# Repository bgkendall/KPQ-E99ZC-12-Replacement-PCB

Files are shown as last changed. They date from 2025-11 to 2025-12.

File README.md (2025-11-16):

# KPQ-E99ZC-12 Replacement PCB

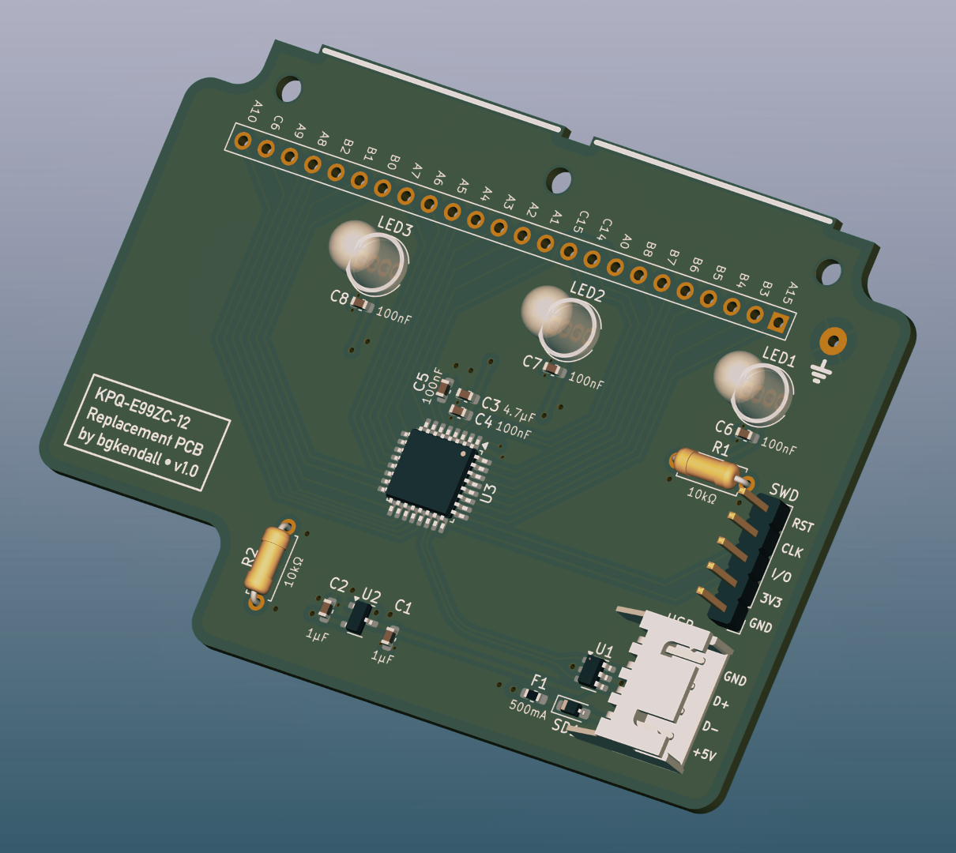
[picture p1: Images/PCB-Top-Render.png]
3D render of PCB viewed from above


## About

This is a replacement PCB for the [Mitsumi KPQ-E99ZC] keyboard of the mid-’90s. This new
PCB uses an STM32C071KBT6 or STM32G0B1KBT6 as the MCU. The pin-outs and behaviour of these
chips are the same and it should be possible to use either chip. The STM32C071 is cheaper,
but is currently (as of November 2025) unsupported by QMK and ZMK.

**CAUTION: Currently this PCB has not been produced and is untested.**

## Requirements

 * [KiCad] v9 or later
 * [BGKiCad library]

[Mitsumi KPQ-E99ZC]: https://web.archive.org/web/20240202015834/https://deskthority.net/wiki/Mitsumi_KPQ-E99ZC
[KiCad]: https://www.kicad.org
[BGKiCad library]: https://github.com/bgkendall/BGKiCad

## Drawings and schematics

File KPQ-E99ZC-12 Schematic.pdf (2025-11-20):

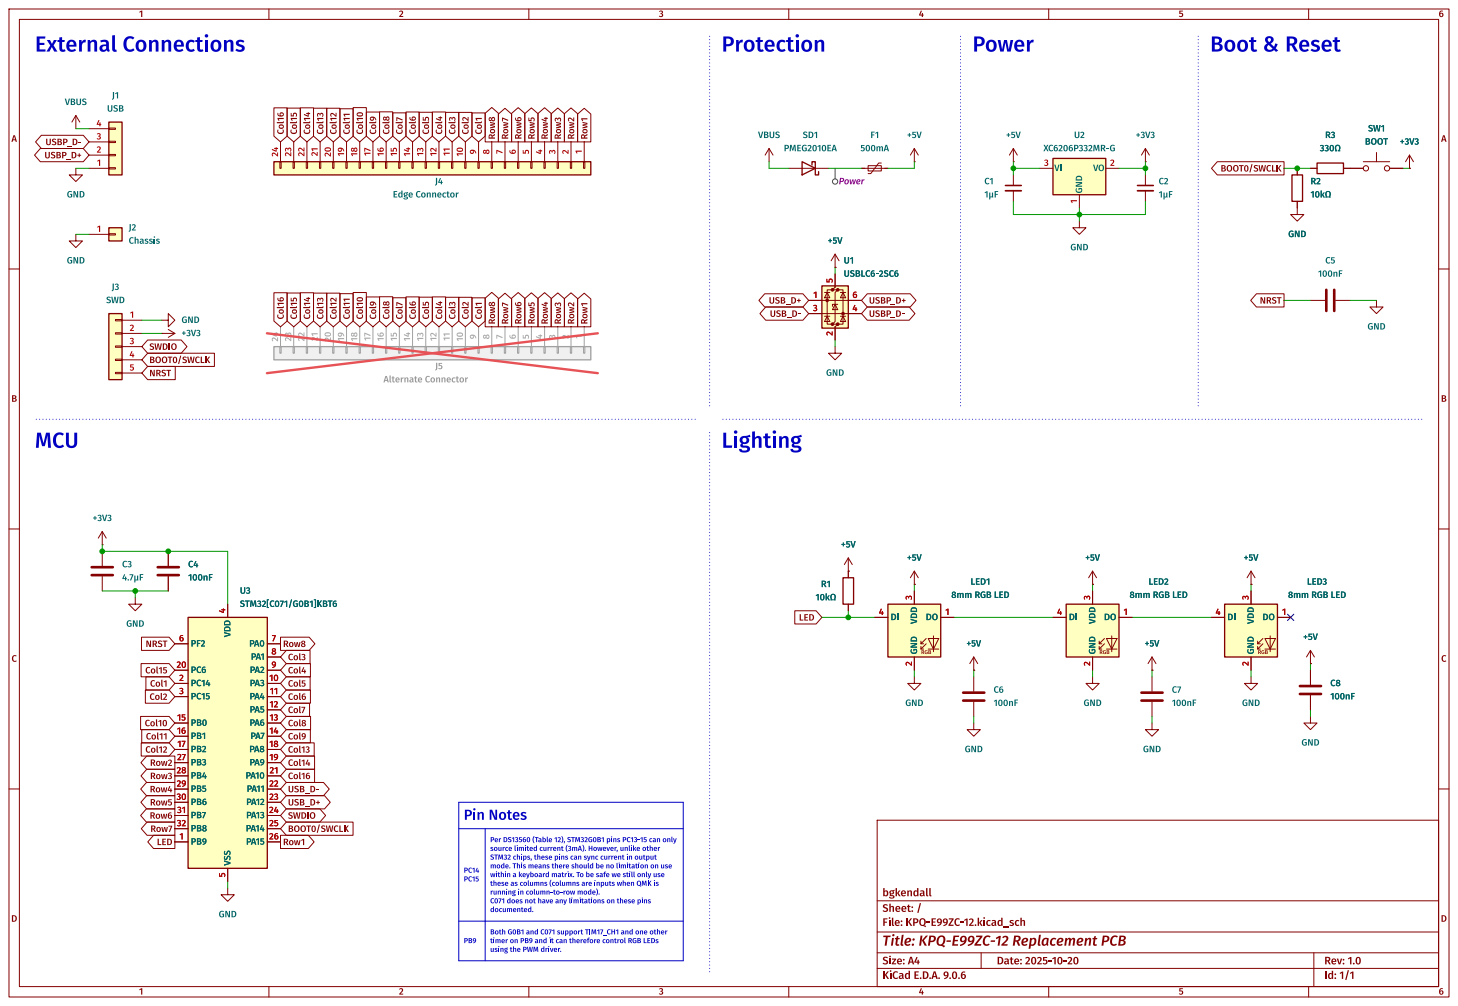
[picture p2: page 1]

source limited current (3mA).However, unlike other STM32chips, these pins can sync current in output mode. This means there should be no limitation on use within a keyboard matrix. Tobe safe we still only use

these as columns (columns are inputs when QMKis

File: KPQ-E99ZC-12.kicad_sch Sheet: / bgkendall

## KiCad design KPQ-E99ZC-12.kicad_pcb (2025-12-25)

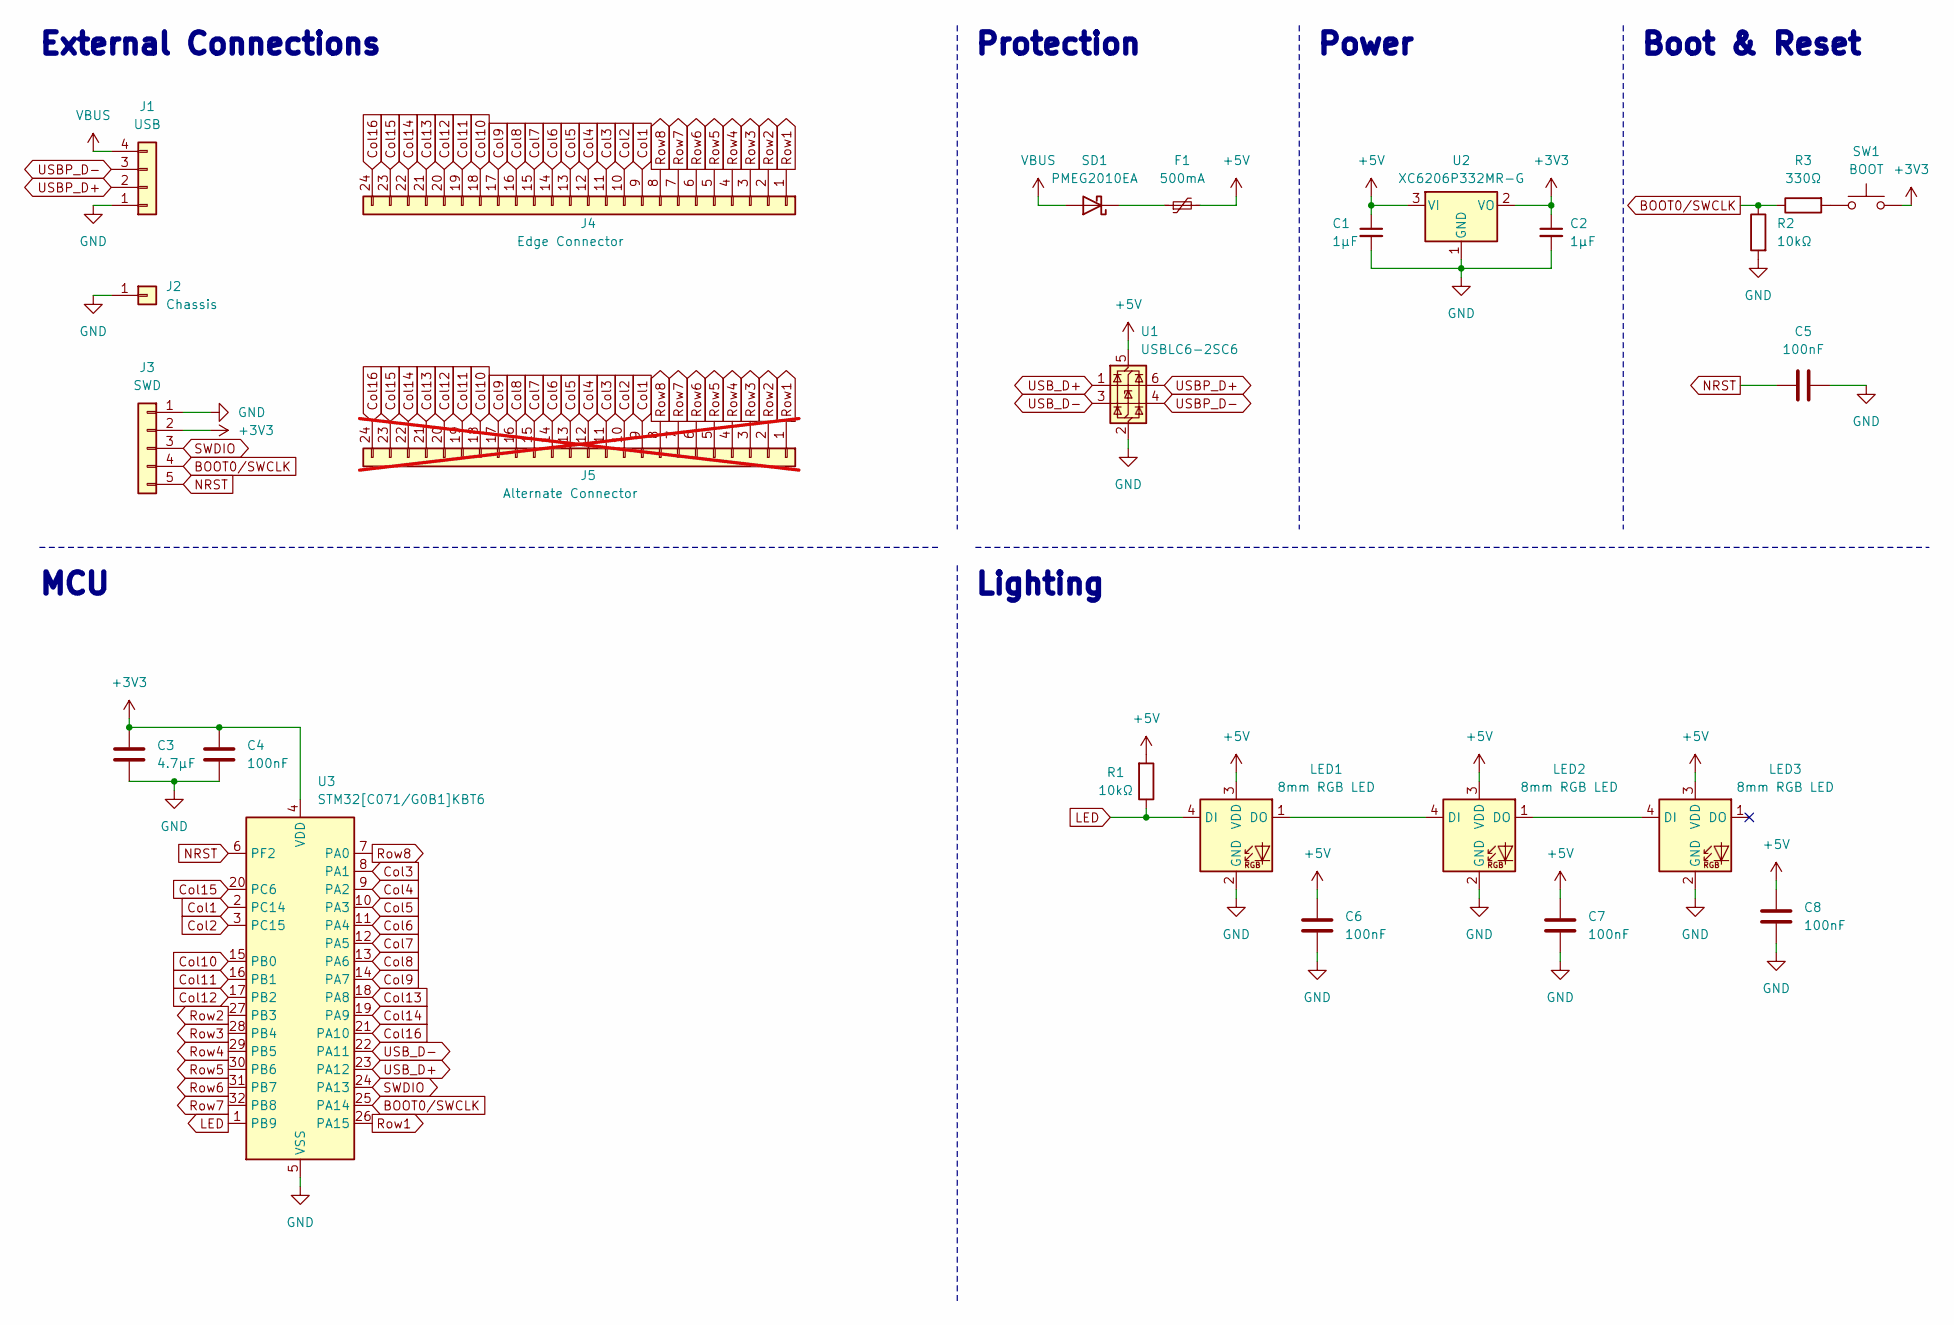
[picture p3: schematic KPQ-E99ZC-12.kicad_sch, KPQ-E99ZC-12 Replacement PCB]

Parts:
C1, C2: 1µF; C_0603_1608Metric; LCSC C52923
C3: 4.7µF; C_0603_1608Metric
C4, C5, C6, C7, C8: 100nF; C_0603_1608Metric
F1: 500mA; Fuse_0603_1608Metric_Pad1.05x0.95mm_HandSolder; LCSC C210357
J1: USB; PinHeader_1x04_P2.54mm_Vertical
J2: Chassis; SolderWire-0.5sqmm_1x01_D0.9mm_OD2.3mm
J3: SWD; PinHeader_1x05_P2.54mm_Vertical
J4: Edge Connector; Edge_Connector_01x24
J5: Alternate Connector; PinHeader_1x24_P2.54mm_Vertical; not fitted
LED1, LED2, LED3: 8mm RGB LED; LED_D5.0mm-4_RGB
R1, R2: 10kΩ; R_Combined_Axial_DIN0207_0603_1608Metric
R3: 330Ω; R_Combined_Axial_DIN0207_0603_1608Metric
SD1: PMEG2010EA; D_SOD-323_HandSoldering; LCSC C2837790
SW1: BOOT; SW_SPST_SKQG_WithStem; LCSC C231329
U1: USBLC6-2SC6; SOT-23-6
U2: XC6206P332MR-G; SOT-23-3
U3: STM32[C071/G0B1]KBT6; LQFP-32_7x7mm_P0.8mm

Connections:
+3V3: C2.1, C3.1, C4.1, J3.2, SW1.2, U2.2 (VO), U3.4 (VDD)
+5V: C1.1, C6.2, C7.2, C8.2, F1.2, LED1.3 (VDD), LED2.3 (VDD), LED3.3 (VDD), R1.2, U1.5 (VBUS), U2.3 (VI)
BOOT0/SWCLK: J3.4, R2.1, R3.1, U3.25 (PA14)
Col1: J4.9, J5.9, U3.2 (PC14)
Col2: J4.10, J5.10, U3.3 (PC15)
Col3: J4.11, J5.11, U3.8 (PA1)
Col4: J4.12, J5.12, U3.9 (PA2)
Col5: J4.13, J5.13, U3.10 (PA3)
Col6: J4.14, J5.14, U3.11 (PA4)
Col7: J4.15, J5.15, U3.12 (PA5)
Col8: J4.16, J5.16, U3.13 (PA6)
Col9: J4.17, J5.17, U3.14 (PA7)
Col10: J4.18, J5.18, U3.15 (PB0)
Col11: J4.19, J5.19, U3.16 (PB1)
Col12: J4.20, J5.20, U3.17 (PB2)
Col13: J4.21, J5.21, U3.18 (PA8)
Col14: J4.22, J5.22, U3.19 (PA9)
Col15: J4.23, J5.23, U3.20 (PC6)
Col16: J4.24, J5.24, U3.21 (PA10)
GND: C1.2, C2.2, C3.2, C4.2, C5.2, C6.1, C7.1, C8.1, J1.1, J2.1, J3.1, LED1.2 (GND), LED2.2 (GND), LED3.2 (GND), R2.2, U1.2 (GND), U2.1 (GND), U3.5 (VSS)
LED: LED1.4 (DI), R1.1, U3.1 (PB9)
NRST: C5.1, J3.5, U3.6 (PF2)
unnamed: LED1.1 (DO), LED2.4 (DI)
unnamed: LED2.1 (DO), LED3.4 (DI)
unnamed: R3.2, SW1.1
unnamed: F1.1, SD1.1 (K)
Row1: J4.1, J5.1, U3.26 (PA15)
Row2: J4.2, J5.2, U3.27 (PB3)
Row3: J4.3, J5.3, U3.28 (PB4)
Row4: J4.4, J5.4, U3.29 (PB5)
Row5: J4.5, J5.5, U3.30 (PB6)
Row6: J4.6, J5.6, U3.31 (PB7)
Row7: J4.7, J5.7, U3.32 (PB8)
Row8: J4.8, J5.8, U3.7 (PA0)
SWDIO: J3.3, U3.24 (PA13)
USBP_D+: J1.2, U1.6 (I/O1)
USBP_D-: J1.3, U1.4 (I/O2)
USB_D+: U1.1 (I/O1), U3.23 (PA12)
USB_D-: U1.3 (I/O2), U3.22 (PA11)
VBUS: J1.4, SD1.2 (A)

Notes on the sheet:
Boot & Reset
MCU
Power
Lighting
Protection
External Connections

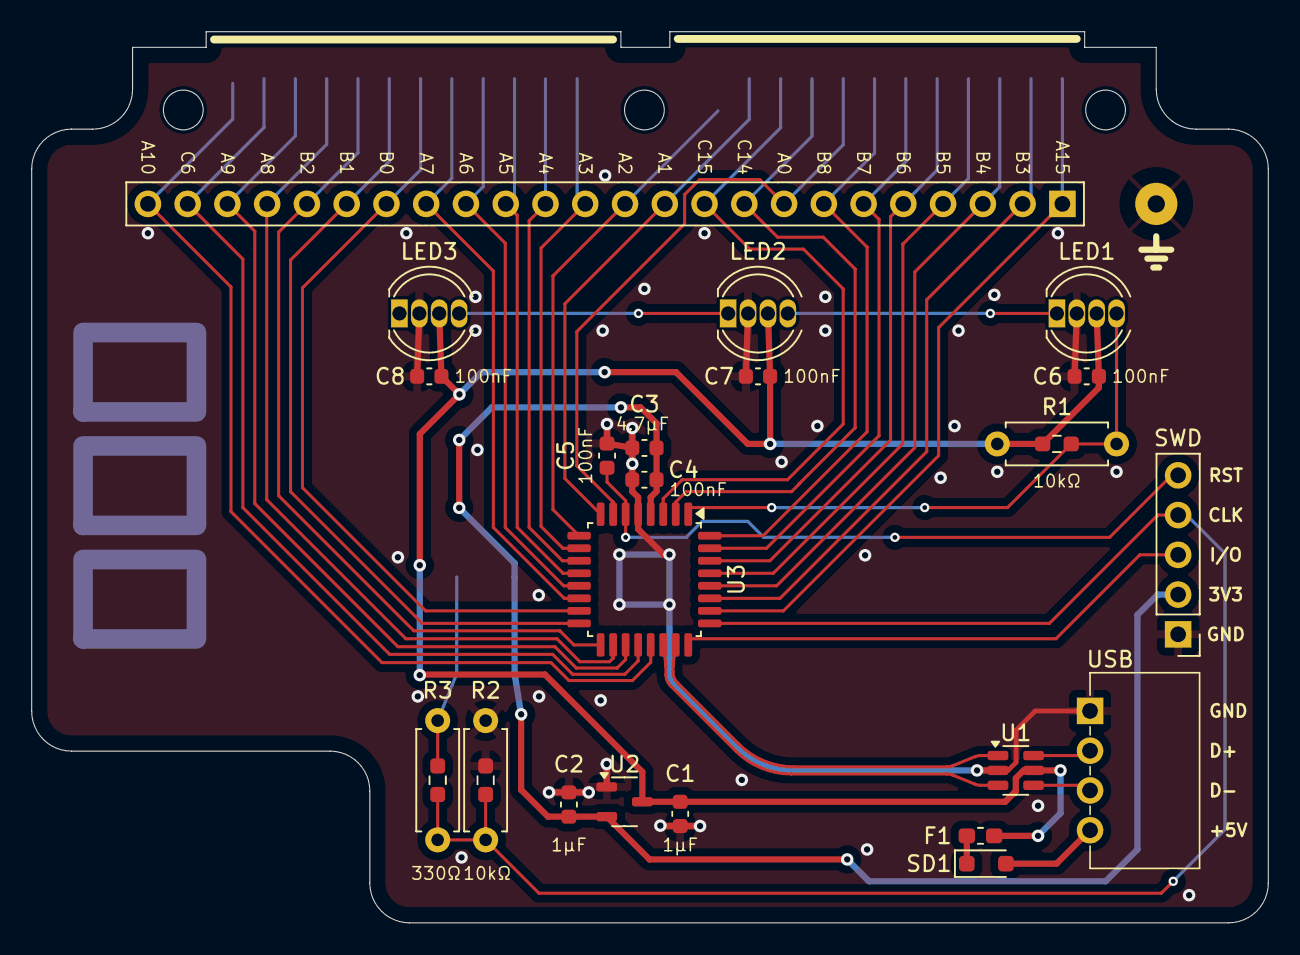
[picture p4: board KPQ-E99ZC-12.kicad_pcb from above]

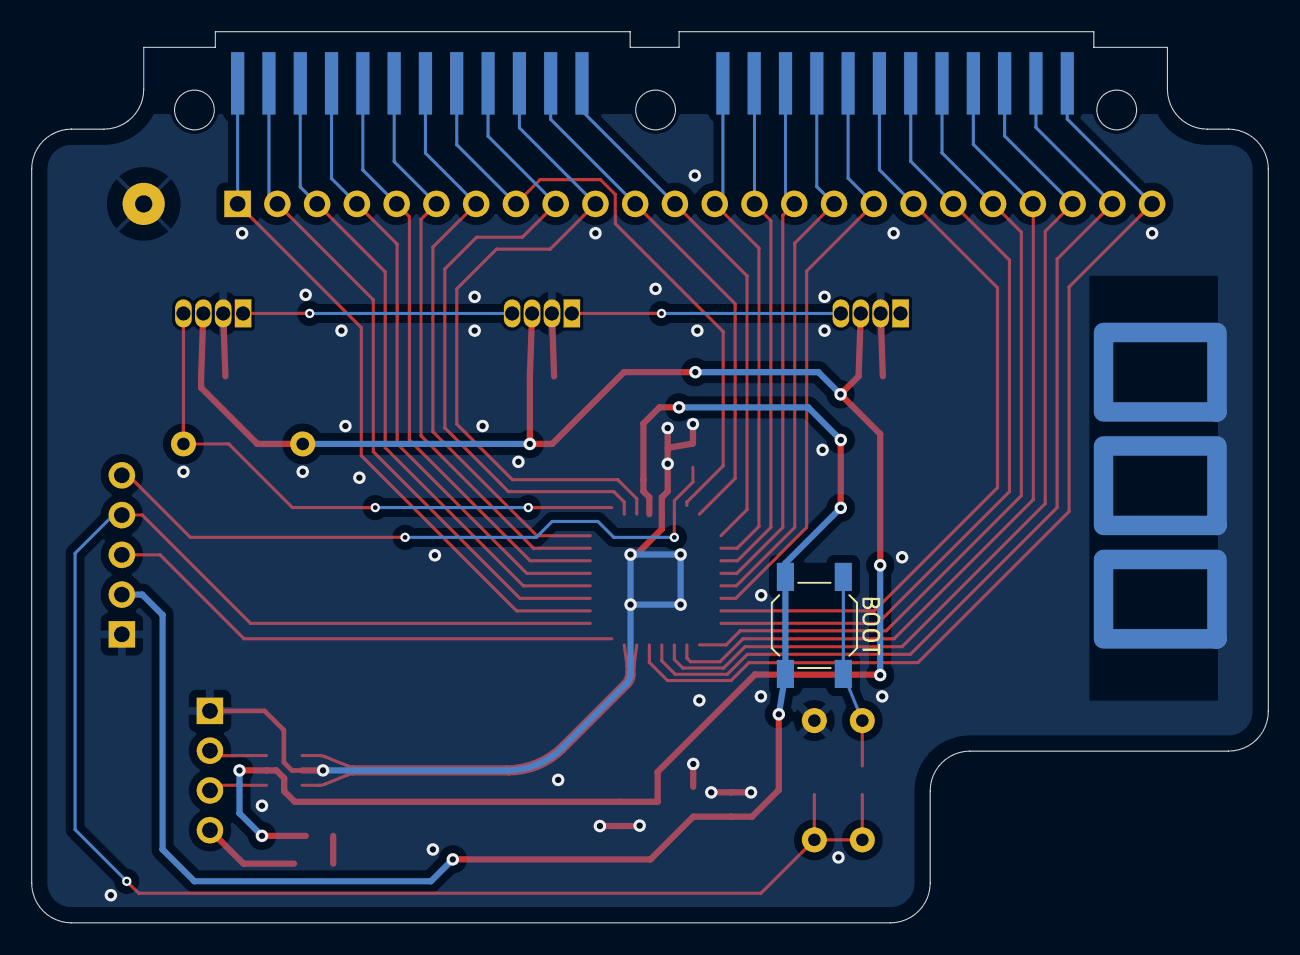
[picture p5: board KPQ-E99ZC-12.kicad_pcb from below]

Board: 2 copper layers, 79.0 x 56.9 mm, 25 parts (2 on the bottom side), 40 nets.

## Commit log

2025-03-03 Add rough draft
    [KPQ-E99ZC-12.kicad_pcb, KPQ-E99ZC-12.kicad_sch]
2025-03-04 Update net classes
    [KPQ-E99ZC-12.kicad_pcb]
2025-03-04 Add measurements and tweak positions
    [KPQ-E99ZC-12.kicad_pcb]
2025-03-04 Swap LED pin
    [KPQ-E99ZC-12.kicad_pcb, KPQ-E99ZC-12.kicad_sch]
2025-03-06 Refine edges and positioning, especially around edge connectors
    [KPQ-E99ZC-12.kicad_pcb, KPQ-E99ZC-12.kicad_sch]
2025-03-11 Add +5V to SWD port, label SWD port, adjust PCB outline
    PCB outline and LED placement adjusted after comparing printout with actual PCB.
    [KPQ-E99ZC-12.kicad_pcb, KPQ-E99ZC-12.kicad_sch]
2025-03-11 Label USB post pins
    [KPQ-E99ZC-12.kicad_pcb, KPQ-E99ZC-12.kicad_sch]
2025-03-11 Remove pull-down resistor on BOOT0
    Since pin 25 is also a GPIO pin it has an internal pull-down resistor. The resistor is engaged on reset to allow for SWCLK functionality.
    [KPQ-E99ZC-12.kicad_pcb, KPQ-E99ZC-12.kicad_sch]
2025-03-11 Add board title, etc., to silkscreen
    Make “ミツミ” a de-boss in the rear copper layer.
    [KPQ-E99ZC-12.kicad_pcb]
2025-03-11 Tweak routing
    [KPQ-E99ZC-12.kicad_pcb]
2025-03-11 Fix DRC errors
    [KPQ-E99ZC-12.kicad_pcb]
2025-03-11 Flip boot switch to back
    This should be accessible through existing holes in the case near the tilt legs.
    [KPQ-E99ZC-12.kicad_pcb]
2025-03-11 Rotate LEDs
    [KPQ-E99ZC-12.kicad_pcb]
2025-03-11 Switch info text to DIN Alternate
    [KPQ-E99ZC-12.kicad_pcb]
2025-03-11 Tweak alignment of J1 and other minor adjustments
    [KPQ-E99ZC-12.kicad_pcb]
2025-03-11 Change R2 to R1 (since the previous R1 has been removed)
    [KPQ-E99ZC-12.kicad_pcb, KPQ-E99ZC-12.kicad_sch]
2025-03-11 Switch info. panel font to Alte DIN 1451 Mittelschrift
    [KPQ-E99ZC-12.kicad_pcb]
2025-03-13 Various tweaks, mostly to silkscreen
    [KPQ-E99ZC-12.kicad_pcb, KPQ-E99ZC-12.kicad_sch]
2025-03-13 Add copper and mask to back of edge connector
    [KPQ-E99ZC-12.kicad_pcb]
2025-03-13 Use correct symbol for RBG LEDs
    !!
    [KPQ-E99ZC-12.kicad_pcb, KPQ-E99ZC-12.kicad_sch]
2025-03-13 Tweak power routing
    [KPQ-E99ZC-12.kicad_pcb]
2025-03-13 Widen +5V routing under U1
    [KPQ-E99ZC-12.kicad_pcb]
2025-03-13 Remove +5V from J3
    This can be accessed via J1, and would avoid +5V being input from both J1 and J3 at the same time.
    [KPQ-E99ZC-12.kicad_pcb, KPQ-E99ZC-12.kicad_sch]
2025-03-13 Tweak “ミツミ” and info. panel
    [KPQ-E99ZC-12.kicad_pcb]
2025-03-15 Move BOOT switch over 1mm after testing with printout
    Plus some other minor tweaks
    [KPQ-E99ZC-12.kicad_pcb]
2025-03-16 Lock components that must not move
    [KPQ-E99ZC-12.kicad_pcb]
2025-03-16 Mark alternate connector as Do Not Populate
    This is mainly so that it can be filtered out of the 3D view!
    [KPQ-E99ZC-12.kicad_sch]
2025-04-29 Minor tweaks
    [KPQ-E99ZC-12.kicad_pcb, KPQ-E99ZC-12.kicad_sch]
2025-05-10 Add additional ground vias and tweak routing
    [KPQ-E99ZC-12.kicad_pcb]
2025-05-31 Add pin labelling to alternate connection
    [KPQ-E99ZC-12.kicad_pcb, KPQ-E99ZC-12.kicad_sch]
2025-07-05 Round USB data lines; other routing tweaks
    [KPQ-E99ZC-12.kicad_pcb]
2025-10-20 Support STM32G0B1KBT6 in addition to STM32C071KBT6
    The pin-out is the same, but the G0B1 datasheet says that pin PC13, PC14 and PC15 should not be used as outputs. The schematic is therefore updated to move Row 8 away from PC14. This requires a littl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
    [KPQ-E99ZC-12.kicad_pcb, KPQ-E99ZC-12.kicad_sch]
2025-10-20 Update global label I/O directions
    [KPQ-E99ZC-12.kicad_sch]
2025-10-20 Change R1 to combined THT/SMT footprint
    [KPQ-E99ZC-12.kicad_pcb, KPQ-E99ZC-12.kicad_sch]
2025-10-20 Add pin notes to schematic
    [KPQ-E99ZC-12.kicad_sch]
2025-10-20 Tidied schematic
    [KPQ-E99ZC-12.kicad_pcb, KPQ-E99ZC-12.kicad_sch]
2025-11-16 Add boot resistor, tweak routing
    [KPQ-E99ZC-12.kicad_pcb, KPQ-E99ZC-12.kicad_sch]
2025-11-16 Add values to resistors, tweak routing
    [KPQ-E99ZC-12.kicad_pcb]
2025-11-16 Remove DRC markers
    [KPQ-E99ZC-12.kicad_pcb]
2025-11-16 Update board render
2025-11-20 Update boot circuit, tweak positioning and routing
    [KPQ-E99ZC-12.kicad_pcb, KPQ-E99ZC-12.kicad_sch]
2025-11-20 Add PDF of schematic
2025-11-26 Updated via size, tweaked routing
    [KPQ-E99ZC-12.kicad_pcb]
2025-11-26 Added custom rule for 5mm RGB LEDs
2025-11-26 Add courtyards to edge connector
2025-12-23 Reroute 5V trace
    [KPQ-E99ZC-12.kicad_pcb]
2025-12-25 Minor routing tweak
    [KPQ-E99ZC-12.kicad_pcb]
